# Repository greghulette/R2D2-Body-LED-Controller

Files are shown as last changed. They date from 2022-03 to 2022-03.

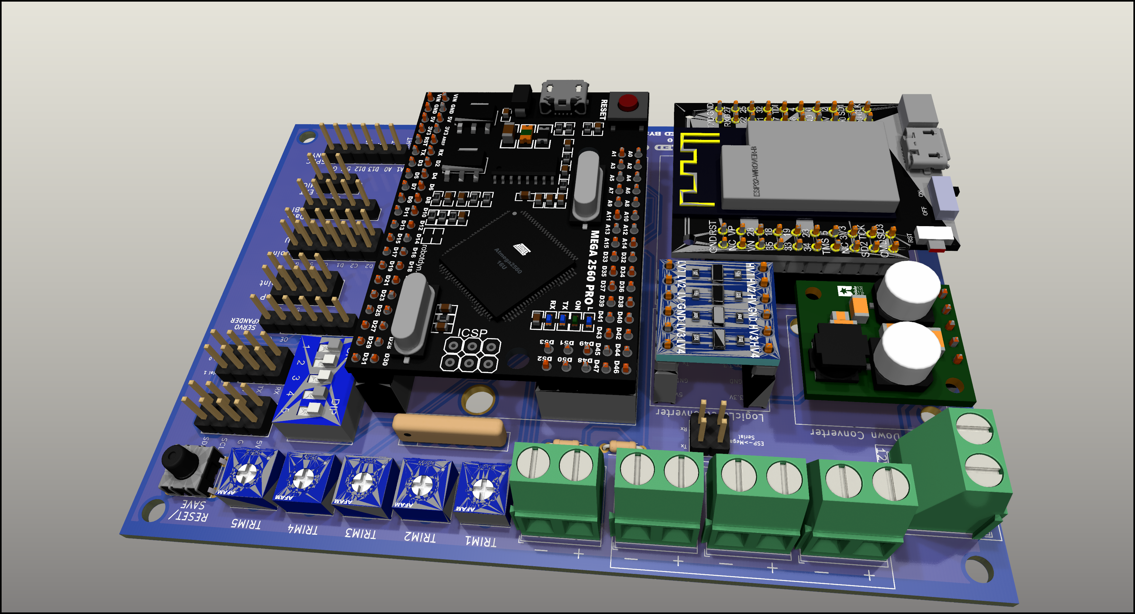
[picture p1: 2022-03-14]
BODY LED CONTROLLER/Body_LED_Controller-V2-1.png

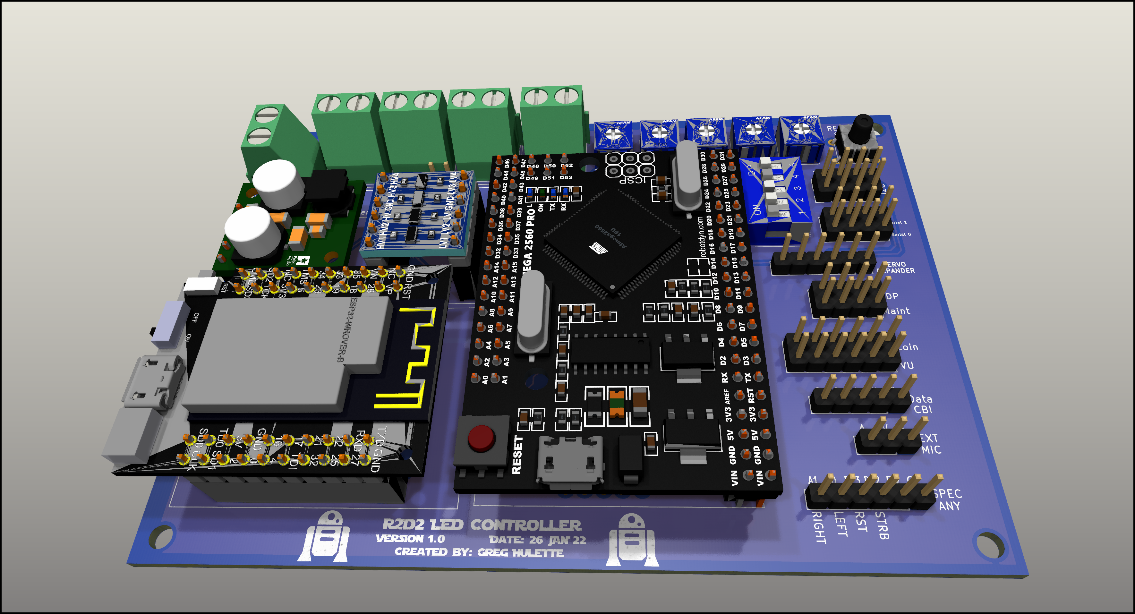
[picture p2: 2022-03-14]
BODY LED CONTROLLER/Body_LED_Controller-V2.png

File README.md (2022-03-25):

# R2D2-Body-LED-Controller
 The main controller and LED boards

The main controller and LED boards. The main controller board is being modified.  This one technically works but obsolete with the code that I wrote.  I am removing the trimpots, dip switch and some other.  The LED boards have been verified.  

These files are for CSR droids.

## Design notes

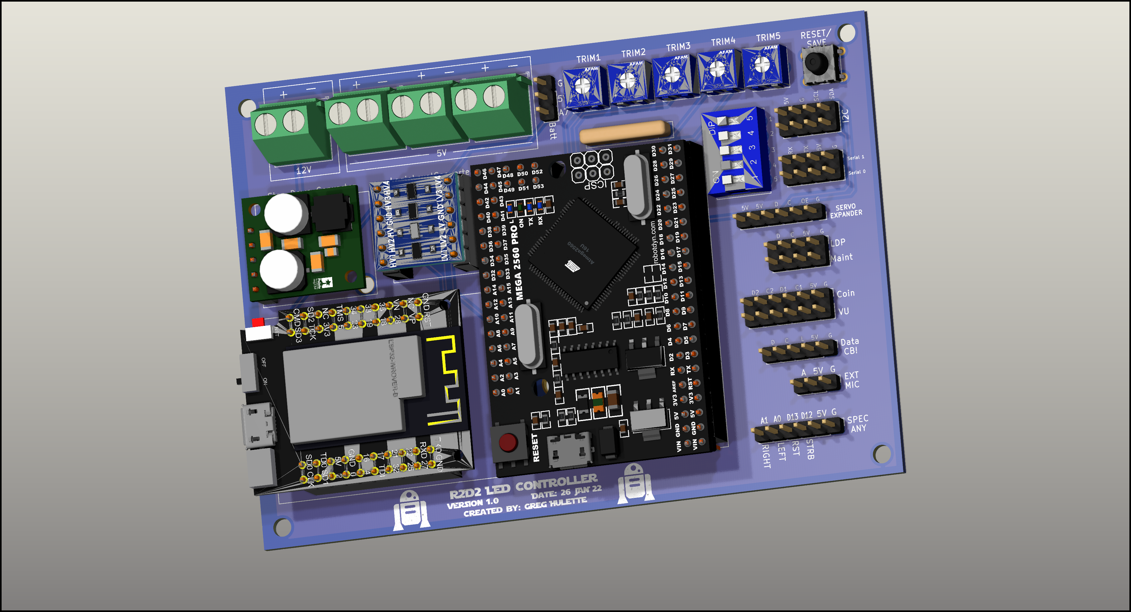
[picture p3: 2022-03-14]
BODY LED CONTROLLER/BODY LED CONTROLLER.png

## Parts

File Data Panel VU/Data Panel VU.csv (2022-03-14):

Id | Designator | Package | Quantity | Designation | Supplier and ref
1 | D18,D5,D10,D15,D8,D3,D14,D11,D4,D6,D1,D13,D17,D7,D16,D12,D9,D2 | LED_RGB_5050-6 | 18 | APA102
2 | J1 | PinHeader_1x06_P2.54mm_Vertical | 1 | Conn_01x06

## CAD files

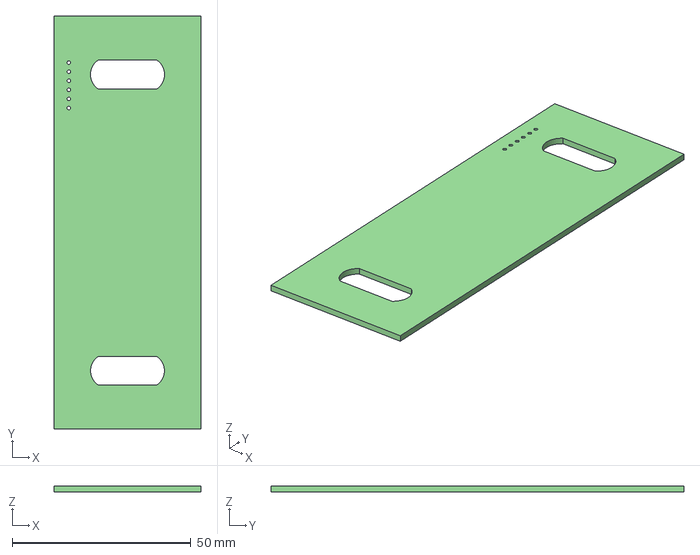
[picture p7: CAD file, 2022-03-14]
Coin_Slots/Coin_Slots.step
41.1 x 115.3 x 1.60 mm

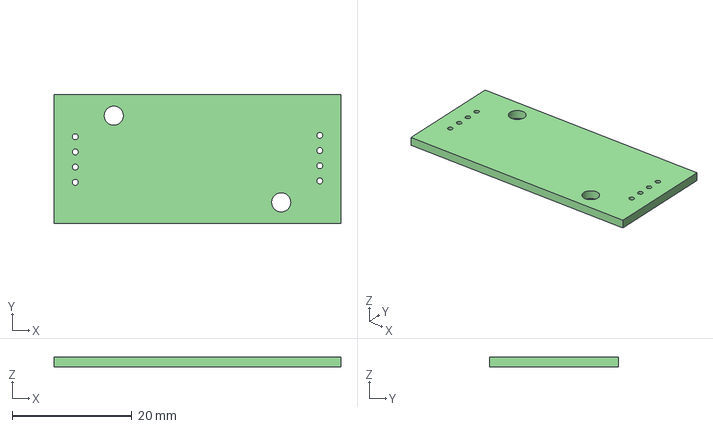
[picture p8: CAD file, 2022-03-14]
Internal Body LED Strips/Internal Body LED Strips.step
48.0 x 21.5 x 1.60 mm

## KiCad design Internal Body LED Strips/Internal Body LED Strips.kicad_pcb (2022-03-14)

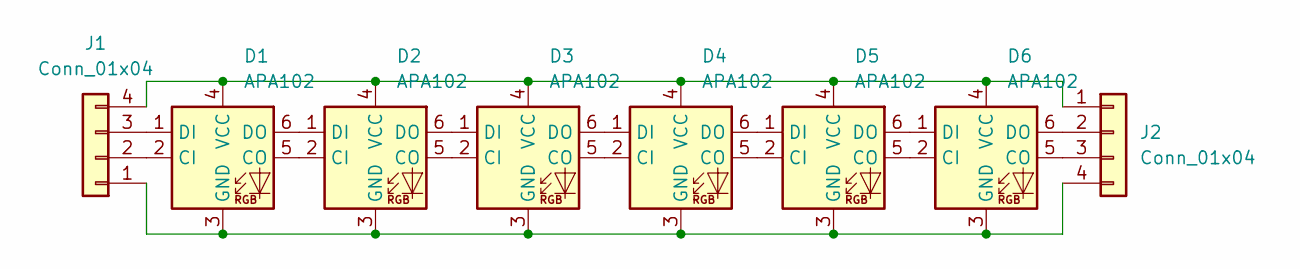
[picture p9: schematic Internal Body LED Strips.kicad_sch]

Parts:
D1, D2, D3, D4, D5, D6: APA102; LED_RGB_5050-6
J1, J2: Conn_01x04; PinHeader_1x04_P2.54mm_Horizontal

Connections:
unnamed: D1.1 (DI), J1.3
unnamed: D1.2 (CI), J1.2
unnamed: D1.3 (GND), D2.3 (GND), D3.3 (GND), D4.3 (GND), D5.3 (GND), D6.3 (GND), J1.1, J2.4
unnamed: D1.4 (VCC), D2.4 (VCC), D3.4 (VCC), D4.4 (VCC), D5.4 (VCC), D6.4 (VCC), J1.4, J2.1
unnamed: D1.5 (CO), D2.2 (CI)
unnamed: D1.6 (DO), D2.1 (DI)
unnamed: D2.5 (CO), D3.2 (CI)
unnamed: D2.6 (DO), D3.1 (DI)
unnamed: D3.5 (CO), D4.2 (CI)
unnamed: D3.6 (DO), D4.1 (DI)
unnamed: D4.5 (CO), D5.2 (CI)
unnamed: D4.6 (DO), D5.1 (DI)
unnamed: D5.5 (CO), D6.2 (CI)
unnamed: D5.6 (DO), D6.1 (DI)
unnamed: D6.5 (CO), J2.3
unnamed: D6.6 (DO), J2.2

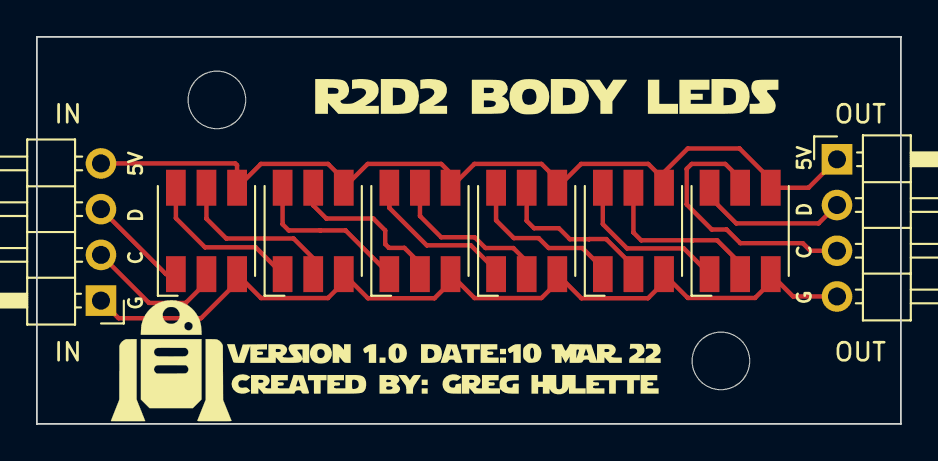
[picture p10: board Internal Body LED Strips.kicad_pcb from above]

Board: 2 copper layers, 48.0 x 21.5 mm, 8 parts (0 on the bottom side), 16 nets.

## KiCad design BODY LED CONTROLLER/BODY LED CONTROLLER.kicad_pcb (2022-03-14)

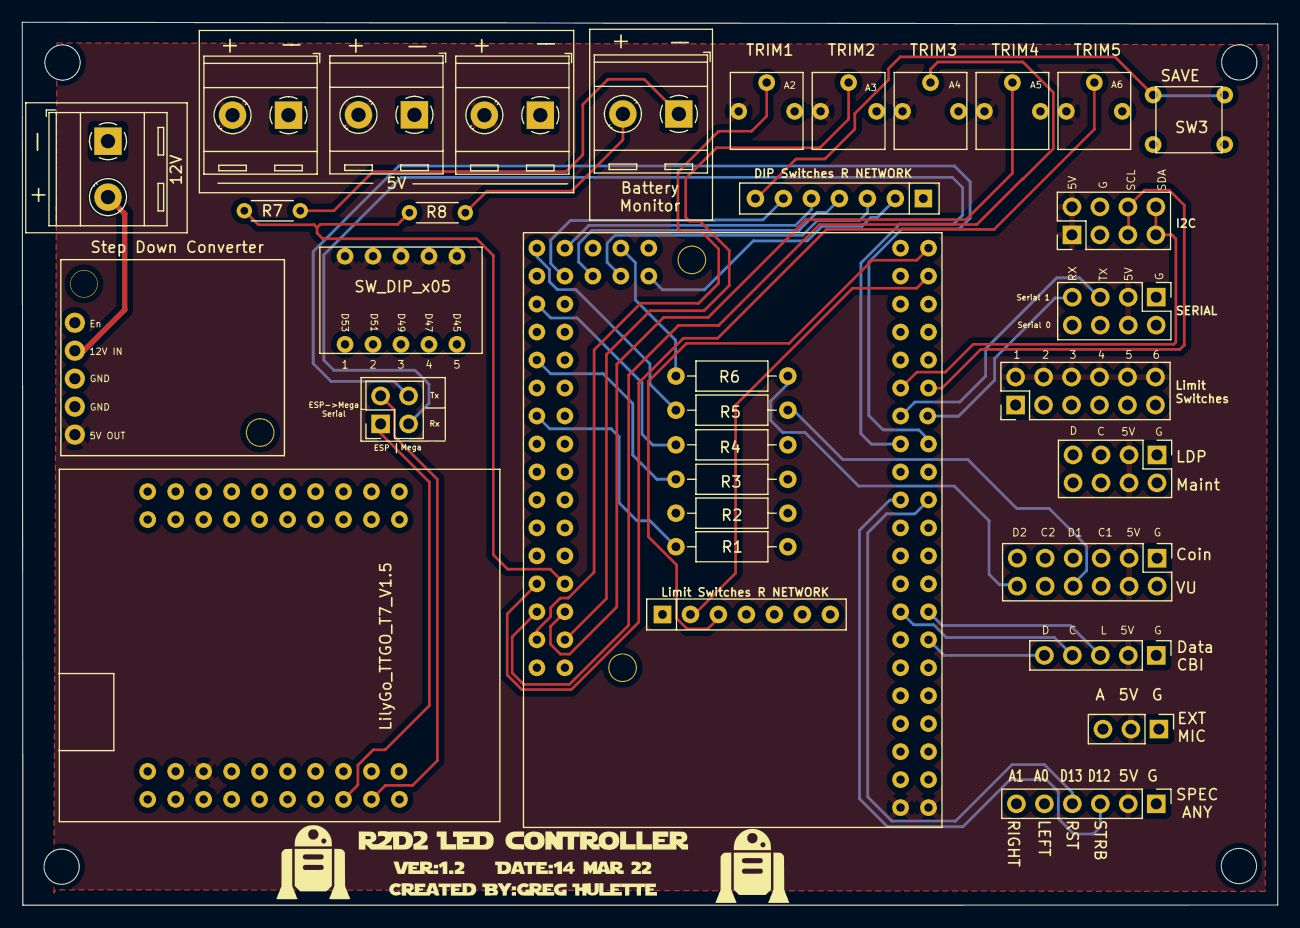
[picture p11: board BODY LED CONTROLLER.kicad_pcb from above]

Board: 4 copper layers, 114.0 x 80.2 mm, 34 parts (0 on the bottom side), 59 nets.

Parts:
J1, J2, J3, J4, J12: Screw_Terminal_01x02; TerminalBlock_RND_205-00287_1x02_P5.08mm_Horizontal
J5: LDP/MAINT; PinHeader_2x04_P2.54mm_Vertical
J6: COIN/VU; PinHeader_2x06_P2.54mm_Vertical
J7: Data Panel/ CBI; PinHeader_1x05_P2.54mm_Vertical
J8: Spectrum Analyzer; PinHeader_1x06_P2.54mm_Vertical
J9: LIMIT; PinHeader_2x06_P2.54mm_Vertical
J10: I2C; PinHeader_2x04_P2.54mm_Vertical
J11: SERIAL; PinHeader_2x04_P2.54mm_Vertical
J13: Conn_02x02_Counter_Clockwise; PinHeader_2x02_P2.54mm_Vertical
J13#2: Conn_01x03; PinHeader_1x03_P2.54mm_Vertical
R1, R2, R3, R4, R5, R6: R_Small_US; R_Axial_DIN0207_L6.3mm_D2.5mm_P10.16mm_Horizontal
R7, R8: R_Small_US; R_Axial_DIN0204_L3.6mm_D1.6mm_P5.08mm_Horizontal
RN1, RN2: R_Network06; R_Array_SIP7
RV1: TRIM1; Potentiometer_Bourns_3362P_Top
RV2: TRIM3; Potentiometer_Bourns_3362P_Top
RV3: TRIM5; Potentiometer_Bourns_3362P_Top
RV4: TRIM2; Potentiometer_Bourns_3362P_Top
RV5: TRIM4; Potentiometer_Bourns_3362P_Top
SW1: SW_DIP_x05; DIP_Switch_TE_5435640-3
SW3: SW_DPST; Schurter_486-3458-ND_Momentary_Switch
U1: D24V550F5_Step_Down_Regulator; VoltageREG_2851
U2: LilyGo_TTGO_T7_V1.5; LILYGO_TTGO_T7_V1.5
U3: Arduino_Mega2560_Mini_Arduino_Mega2560_Mini; Arduino_Mega_2560_Pro_MINI-Updated-Corrrect

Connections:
+5V: J2.2, J3.2, J4.2, J5.3, J5.4, J6.3, J6.4, J7.2, J8.2, J9.2, J9.4, J9.6, J9.8, J9.10, J9.12, J10.1, J10.2, J11.3, J11.4, J13#2.2, RV1.3, RV2.3, RV3.3, RV4.3, RV5.3, SW1.6, SW1.7, SW1.8, SW1.9, SW1.10, U1.Vout (VOut), U2.70 (5V), U3.70 (VIN), U3.71 (VIN)
+12V: J1.2, U1.VIN
BATTERY_LEVEL: R7.1, R8.2, U3.207 (A7)
CS1_CLOCK: J6.5, U3.40 (D40)
CS1_DATA: R3.2, U3.38 (D38)
CS2_CLOCK: J6.9, U3.44 (D44)
CS2_DATA: R4.2, U3.42 (D42)
DP_CLOCK: J7.4, U3.4 (D4)
DP_DATA_IN: J7.5, U3.3 (D3)
DP_LOAD: J7.3, U3.5 (D5)
ESP_LOGIC_RX: J13.1, U2.251 (GPIO25_1)
ESP_LOGIC_TX: J13.2, U2.271 (GPIO27_1)
EXT_MIC: J13#2.3, U3.208 (A8)
GND: J1.1, J2.1, J3.1, J4.1, J5.1, J5.2, J6.1, J6.2, J7.1, J8.1, J10.3, J10.4, J11.1, J11.2, J13#2.1, RN1.1 (common), RN2.1 (common), RV1.1, RV2.1, RV3.1, RV4.1, RV5.1, SW3.1, SW3.3, U1.GND1 (GND), U1.GND2 (GND), U2.60 (GND), U2.61 (GND), U2.62 (GND), U3.62 (GND), U3.63 (GND)
JUMPER1: RN1.2 (R1), SW1.5, U3.53 (D53)
JUMPER2: RN1.3 (R2), SW1.4, U3.51 (D51)
JUMPER3: RN1.4 (R3), SW1.3, U3.49 (D49)
JUMPER4: RN1.5 (R4), SW1.2, U3.47 (D47)
JUMPER5: RN1.6 (R5), SW1.1, U3.45 (D45)
LDP_CLOCK: J5.5, U3.36 (D36)
LDP_DATA: R1.2, U3.34 (D34)
LIMIT1: J9.1, RN2.2 (R1), U3.29 (D29)
LIMIT2: J9.3, RN2.3 (R2), U3.31 (D31)
LIMIT3: J9.5, RN2.4 (R3), U3.33 (D33)
LIMIT4: J9.7, RN2.5 (R4), U3.35 (D35)
LIMIT5: J9.9, RN2.6 (R5), U3.37 (D37)
LIMIT6: J9.11, RN2.7 (R6), U3.39 (D39)
LOGIC_2560_RX: J13.3, U3.16 (D16)
LOGIC_2560_TX: J13.4, U3.17 (D17)
MAINT_CLOCK: J5.6, U3.32 (D32)
MAINT_DATA: R2.2, U3.30 (D30)
NEG: J12.2, R8.1
unnamed: J5.7, R1.1
unnamed: J5.8, R2.1
unnamed: J6.7, R3.1
unnamed: J6.8, R5.1
unnamed: J6.11, R4.1
unnamed: J6.12, R6.1
POS: J12.1, R7.2
RX0: J11.8, U3.1 (TX)
RX1: J11.7, U3.19 (D19)
SAVE: RN1.7 (R6), SW3.2, SW3.4, U3.41 (D41)
SCL: J10.5, J10.6, U3.21 (D21)
SDA: J10.7, J10.8, U3.20 (D20)
SPECTRUM_LEFT: J8.5, U3.200 (A0)
SPECTRUM_RIGHT: J8.6, U3.201 (A1)
TRIM1: RV1.2, U3.202 (A2)
TRIM2: RV4.2, U3.203 (A3)
TRIM3: RV2.2, U3.204 (A4)
TRIM4: RV5.2, U3.205 (A5)
TRIM5: RV3.2, U3.206 (A6)
TX0: J11.6, U3.0 (RX)
TX1: J11.5, U3.18 (D18)
VU1_CLOCK: J6.6, U3.48 (D48)
VU1_DATA: R5.2, U3.46 (D46)
VU2_CLOCK: J6.10, U3.52 (D52)
VU2_DATA: R6.2, U3.50 (D50)
VU_RESET: J8.4, U3.13 (D13)
VU_STROBE: J8.3, U3.12 (D12)

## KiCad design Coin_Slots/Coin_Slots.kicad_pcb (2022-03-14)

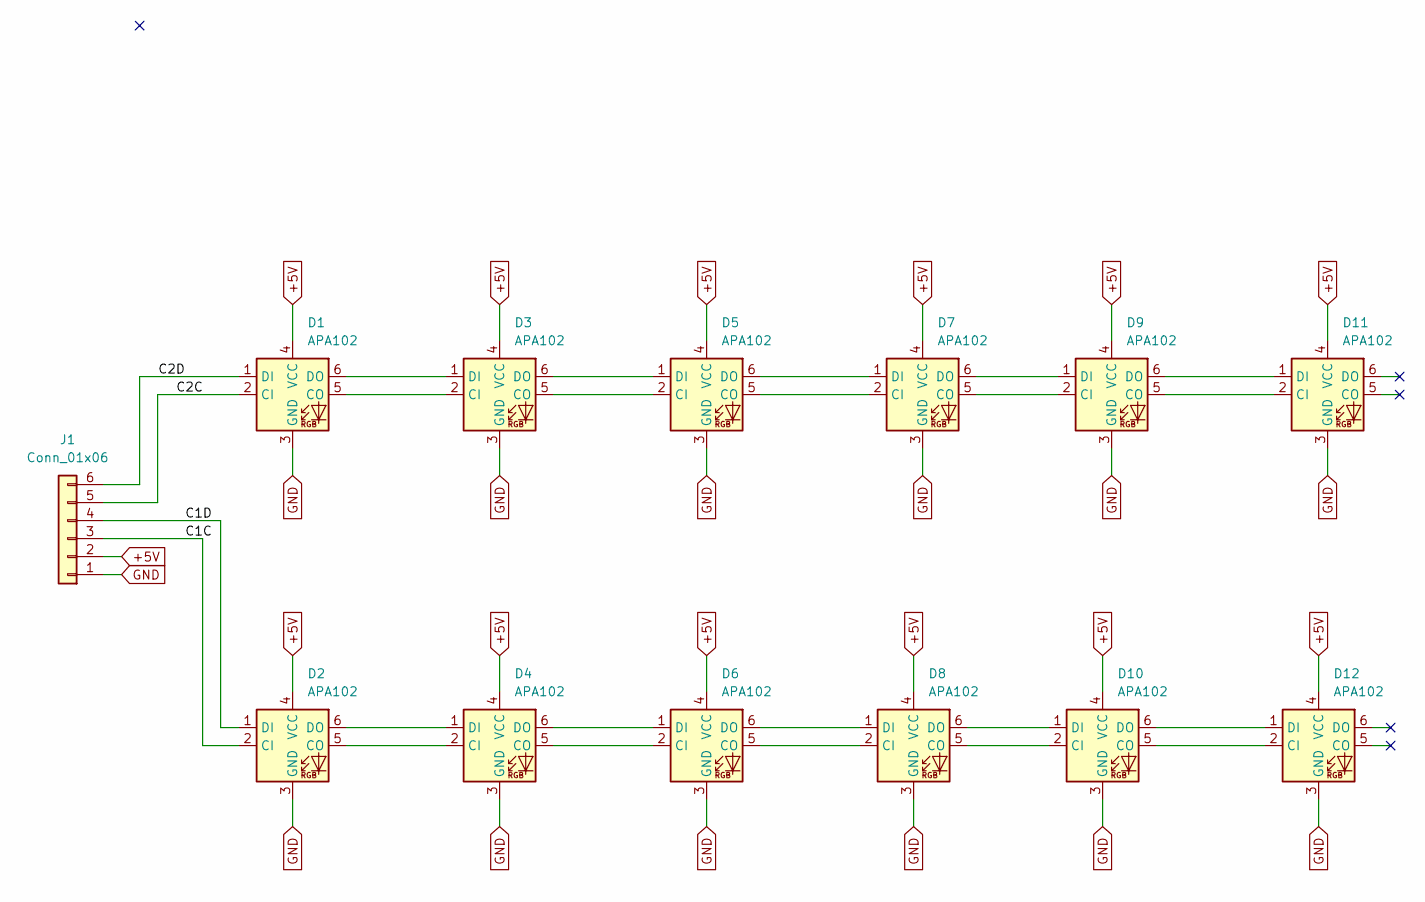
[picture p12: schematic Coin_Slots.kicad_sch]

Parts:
D1, D2, D3, D4, D5, D6, D7, D8, D9, D10, D11, D12: APA102; LED_RGB_5050-6
J1: Conn_01x06; PinHeader_1x06_P2.54mm_Vertical

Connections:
+5V: D1.4 (VCC), D2.4 (VCC), D3.4 (VCC), D4.4 (VCC), D5.4 (VCC), D6.4 (VCC), D7.4 (VCC), D8.4 (VCC), D9.4 (VCC), D10.4 (VCC), D11.4 (VCC), D12.4 (VCC), J1.2
/C1C: D2.2 (CI), J1.3
/C1D: D2.1 (DI), J1.4
/C2C: D1.2 (CI), J1.5
/C2D: D1.1 (DI), J1.6
GND: D1.3 (GND), D2.3 (GND), D3.3 (GND), D4.3 (GND), D5.3 (GND), D6.3 (GND), D7.3 (GND), D8.3 (GND), D9.3 (GND), D10.3 (GND), D11.3 (GND), D12.3 (GND), J1.1
unnamed: D1.5 (CO), D3.2 (CI)
unnamed: D1.6 (DO), D3.1 (DI)
unnamed: D2.5 (CO), D4.2 (CI)
unnamed: D2.6 (DO), D4.1 (DI)
unnamed: D3.5 (CO), D5.2 (CI)
unnamed: D3.6 (DO), D5.1 (DI)
unnamed: D4.6 (DO), D6.1 (DI)
unnamed: D4.5 (CO), D6.2 (CI)
unnamed: D5.6 (DO), D7.1 (DI)
unnamed: D5.5 (CO), D7.2 (CI)
unnamed: D6.6 (DO), D8.1 (DI)
unnamed: D6.5 (CO), D8.2 (CI)
unnamed: D7.6 (DO), D9.1 (DI)
unnamed: D7.5 (CO), D9.2 (CI)
unnamed: D9.5 (CO), D11.2 (CI)
unnamed: D9.6 (DO), D11.1 (DI)
unnamed: D8.6 (DO), D10.1 (DI)
unnamed: D8.5 (CO), D10.2 (CI)
unnamed: D10.6 (DO), D12.1 (DI)
unnamed: D10.5 (CO), D12.2 (CI)

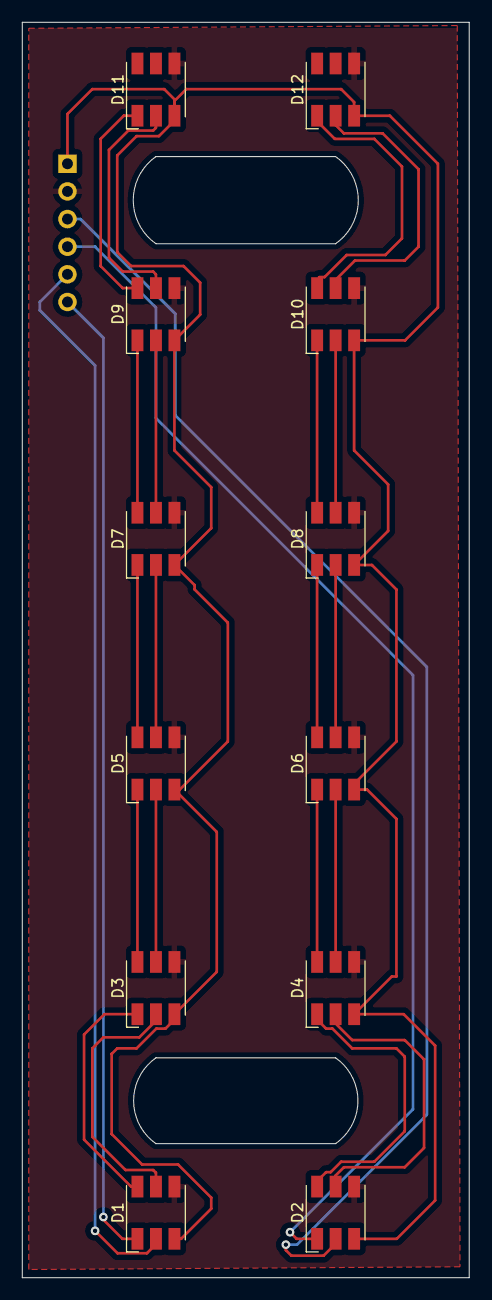
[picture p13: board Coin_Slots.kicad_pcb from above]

Board: 2 copper layers, 41.1 x 115.3 mm, 13 parts (1 on the bottom side), 26 nets.
